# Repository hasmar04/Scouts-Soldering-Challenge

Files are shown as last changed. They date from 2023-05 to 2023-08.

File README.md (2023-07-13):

# Scouts-Soldering-Challenge

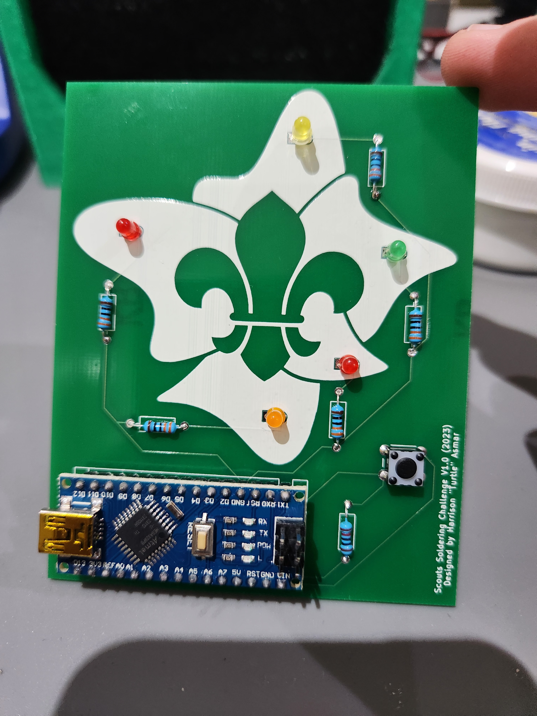
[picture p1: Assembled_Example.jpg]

 
A soldering challenge suitable for Scouts all the way to Rovers.

As a member of the Australian Scouting movement, the logo has been used within this design for the purpose of promoting the movement, and to help the project to the target audience of Scouting members. 

For more information and/or assistance with implementing this challenge in your own Scout group, contact me at [246328@scoutsqld.com.au](mailto:246328@scoutsqld.com.au) 

### For more information on the Australian Scouting Movement, visit https://scouts.com.au

## Components Required
- 1x PCB (see 'pcb' folder)
- 2x Red LED
- 1x Green LED
- 1x Yellow LED
- 1x Orange LED
- 5x 330 ohm resistor
- 1x 10k ohm resistor
- 1x 6x6mm push button
- 1x Arduino Nano

More information can be found in the [Procurement Guide](https://github.com/hasmar04/Scouts-Soldering-Challenge/blob/main/docs/Procurement%20Guide.md)

## Documentation
Documentation can be found in the [/docs](<https://github.com/hasmar04/Scouts-Soldering-Challenge/tree/main/docs>) folder. This includes:
- Arduino IDE Installation and Getting Started
- Arduino Programming Fundamentals
- Procurement Guide
- Assembly Guide

## Contributing
If there is anything that you think is missing from this repository, or you find an error, please [create an issue](<https://github.com/hasmar04/Scouts-Soldering-Challenge/issues>) or fix it yourself and create a pull request.

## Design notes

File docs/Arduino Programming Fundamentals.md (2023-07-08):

# Arduino Programming Fundamentals

## Key Terminology
### Variable
A name that represents a value. Think of it like algebra, where `a` could equal any number, but `a` can also equal words too. Variables can also be changed as the program runs. 
### Library
A set of commands. A library can contain commands that are relevant to each other, such as `Serial` containing commands to do with the Serial Monitor. Think of it like a real library, but instead of books it contains different commands. 

## Key Commands
### I/O (Input, Output)
```
pinMode(PinNumber, Mode)
```
Sets a pin to be either an INPUT or an OUTPUT. 

e.g. `pinMode(2, OUTPUT);`
```
digitalRead(PinNumber)
```
Read the value of the specified PinNumber. This value is usually saved to a variable or used as part of another command. 

e.g. `state = digitalRead(3);`
```
digitalWrite(PinNumber, STATE)
```
Set the digital pin PinNumber to the state HIGH (on) or LOW (off). 

e.g. `digitalWrite(2, HIGH);`

### Serial (Debugging)
#### NOTE: Libraries, Commands and Variable names are all case sensitive, and Serial uses a capital letter!
```
Serial.begin(baud)
```
Begins a Serial transmission over the USB connection to the computer. If using, always use in the `setup()` section. The typical baud rate is 9600. Must be used for other Serial commands to work. 

e.g. `Serial.begin(9600);`
```
Serial.println(string)
```
Prints whatever string (text surrounded by “”) to the serial monitor in the Arduino IDE. Also makes each new command use a new line to make it easier to follow. 

e.g. `Serial.println(“Hello World!”);`

### Other
```
delay(time)
```
Make the program wait for the specified amount of milliseconds (1000 = 1 sec) before proceeding onto the next line.  

e.g. `delay(1000);`

## File Layout
After creating a new file, you will notice that there are two sections, labelled `setup()` and `loop()`. The only things that do **NOT** go in one of these sections are **GLOBAL** variables, i.e. variables that need to be accessible by all parts of the code. All other code, at least for these basic programs, **MUST** go in one of these sections. This includes **CHANGING** the values of those global variables. 

The `setup()` section contains all the code that only runs **ONCE**, such as setting pins to the right modes and enabling `Serial`. 

The `loop()` section, as the name implies, contains all code that is meant to run **FOREVER**. This will be where the bulk of the code should be, such as reading inputs and changing outputs. 

`if()` statements are a form of logic, which allows a program to change it’s behaviour based on if something else is or isn’t true. They only run once, then continue through the rest of the code. For example, if you want to turn the LED on when it is pressed, you could write:
```
if (button == HIGH) {
	digitalWrite(ledRed, HIGH);
}
```
Firstly, you may notice that there are two equals (=) signs. In the Arduino IDE, a single equals is for **SETTING** a value (e.g. Pin = 2), while double equals is for checking if the values are the same as part of logic. 

You will also notice that there are a set of {} brackets, which is how the program knows where the if() statement starts and ends. 

As an extension of `if()` statements, `else if()` can be used for alternative sets of code which can run if the statement provided is true. These run in the order they are found in the code, and the first one that is found to be true will be the **ONLY** one to run. If you want multiple statements which can all run if they are all true, then use multiple `if()` statements instead. 
```
if (button == HIGH) {
	digitalWrite(ledRed, HIGH);
}
else if (button == LOW) {
	digitalWrite(ledRed, LOW);
}
```
`else()` statements are always the last statement in a `if()` statement set, as it is the catch-all for if nothing else is true. For instance, with the example from earlier, if we wanted to turn the light off when the button is **NOT** pressed:
```
if (button == HIGH) {
	digitalWrite(ledRed, HIGH);
}
else {
	digitalWrite(ledRed, LOW);
}
```

Unlike `if()` statements, `while()` loops run through whatever code is contained within them until the statement is no longer true. Any code **AFTER** the `while()` loop will not be run until the statement is no longer true. 
```
while (button == HIGH) {
	digitalWrite(ledRed, HIGH);
}
digitalWrite(ledRed, LOW);
```
For instance, the code above is another way that an LED could be turned on when the button is pressed, and turned off when it is released. The code within the `while()` loop will only run when the statement is true, and the code outside of it will run whenever that statement is not true.

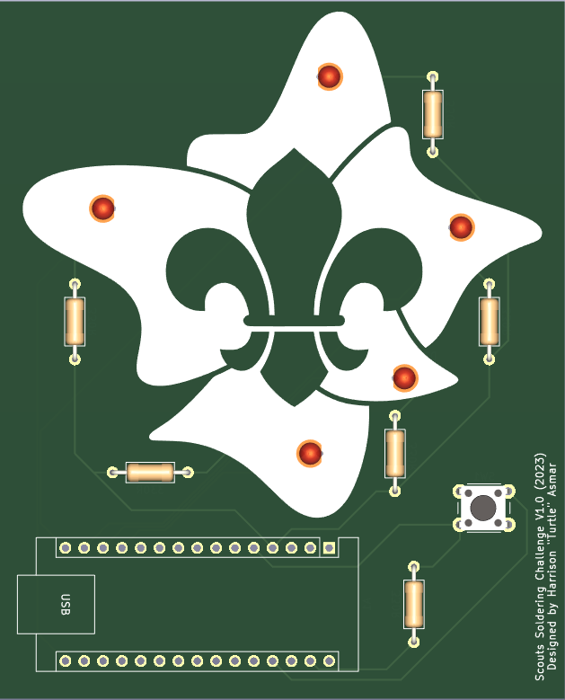
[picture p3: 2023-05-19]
PCB-V1.0.png

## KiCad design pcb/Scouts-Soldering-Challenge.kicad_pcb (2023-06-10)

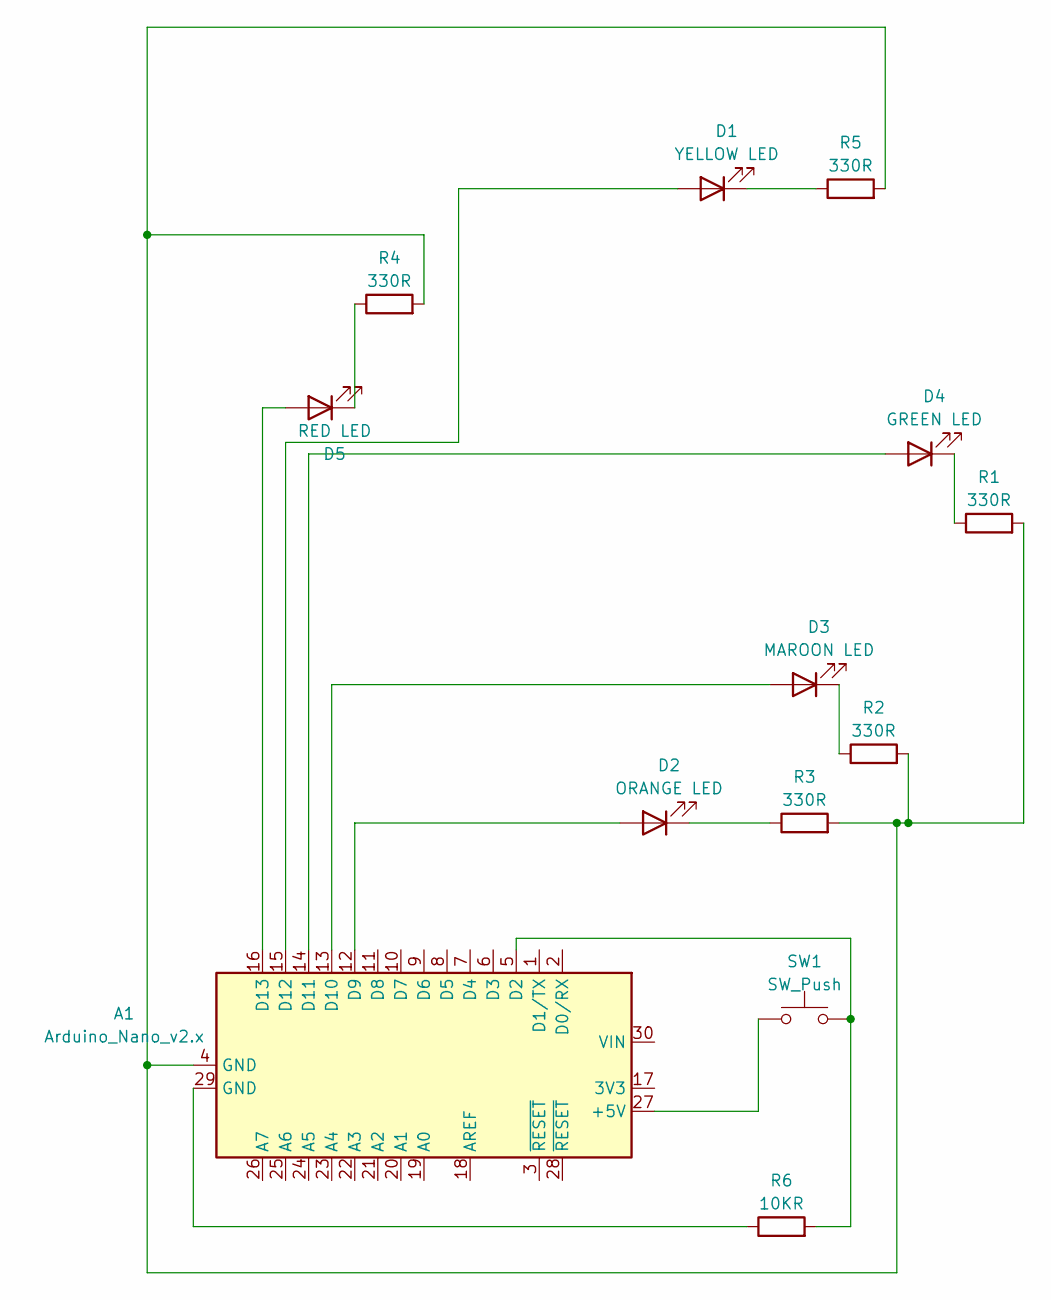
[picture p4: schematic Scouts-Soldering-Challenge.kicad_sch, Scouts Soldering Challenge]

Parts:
A1: Arduino_Nano_v2.x; Arduino_Nano
D1: YELLOW LED; LED_D3.0mm
D2: ORANGE LED; LED_D3.0mm
D3: MAROON LED; LED_D3.0mm
D4: GREEN LED; LED_D3.0mm
D5: RED LED; LED_D3.0mm
R1, R2, R3, R4, R5: 330R; R_Axial_DIN0207_L6.3mm_D2.5mm_P10.16mm_Horizontal
R6: 10KR; R_Axial_DIN0207_L6.3mm_D2.5mm_P10.16mm_Horizontal
SW1: SW_Push; SW_PUSH_6mm

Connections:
unnamed: A1.27 (+5V), SW1.1
unnamed: A1.5 (D2), R6.2, SW1.2
unnamed: A1.12 (D9), D2.2 (A)
unnamed: A1.13 (D10), D3.2 (A)
unnamed: A1.14 (D11), D4.2 (A)
unnamed: A1.15 (D12), D1.2 (A)
unnamed: A1.16 (D13), D5.2 (A)
unnamed: A1.4 (GND), R1.2, R2.2, R3.2, R4.2, R5.2
unnamed: A1.29 (GND), R6.1
unnamed: D1.1 (K), R5.1
unnamed: D2.1 (K), R3.1
unnamed: D3.1 (K), R2.1
unnamed: D4.1 (K), R1.1
unnamed: D5.1 (K), R4.1

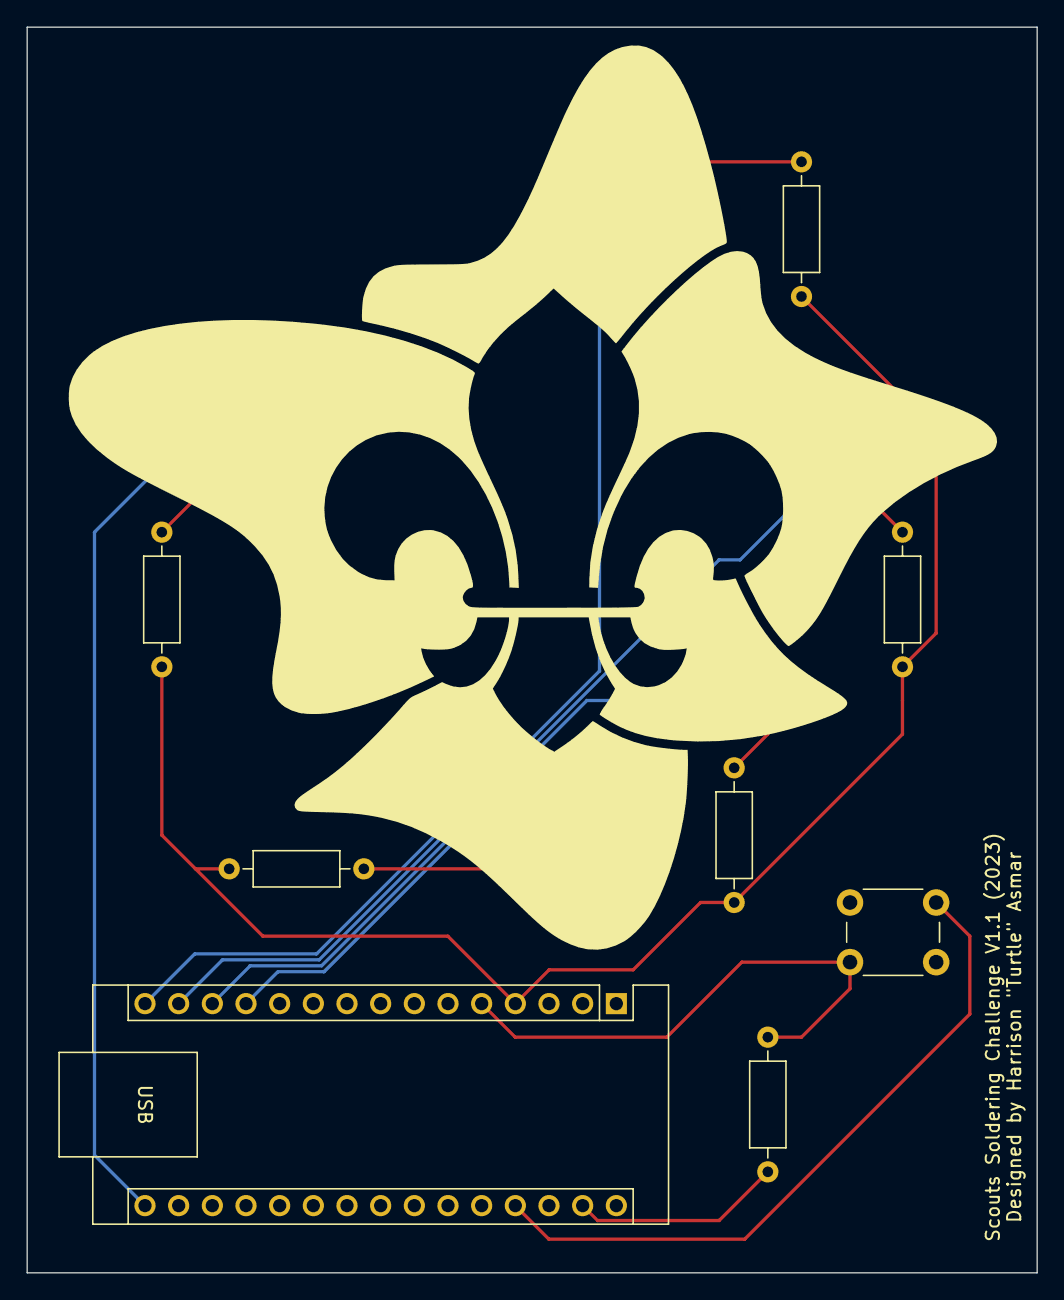
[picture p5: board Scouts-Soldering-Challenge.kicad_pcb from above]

Board: 2 copper layers, 76.2 x 94.0 mm, 13 parts (0 on the bottom side), 14 nets.

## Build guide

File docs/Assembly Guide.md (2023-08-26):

# Assembly Guide
## Before Proceeding
Ensure that you have all components listed in the [Procurement Guide](https://github.com/hasmar04/Scouts-Soldering-Challenge/blob/main/docs/Procurement%20Guide.md), as well as a soldering iron and some solder. Lead-free solder is recommended, although it does require a higher temperature on the soldering iron. 
## Step 1: Test Arduinos
Before starting on the assembly, it is a good idea to test the Arduinos to ensure they are functioning correctly and code can be uploaded to them. It is recommended to upload the boardTest code by following the [Arduino IDE Installation and Getting Started](https://github.com/hasmar04/Scouts-Soldering-Challenge/blob/main/docs/Arduino%20IDE%20Installation%20&%20Getting%20Started%20V1.0.pdf) guide. 
## Step 2: Sort Components Into Sets
This is recommended to be done before the night to make it easier to get the Scouts started on the project. Check out the [README](../README.md) for the list of required components. 
## Step 3: Start with the Resistors
It is always a good idea to start with the flattest components, which in this project are the resistors. There is no wrong orientation to install them, but make sure the correct resistors are installed in the correct places. Poke the legs of the resistor through the holes, trying to make it as flat against the PCB as possible. Once in place, solder from the back side of the PCB and cut the excess legs off with sidecutters. 
## Step 4: Move onto the LEDs
The LEDs are the next tallest components, and require slighly more care than the resistors to install. Ensure the short leg of the LED goes to the square pad, putting it the other way around will not work. The legs can be bent to hold it in place. Once soldered in place, cut off extra leg length with sidecutters. For future reference, the square pad is typically for Ground, and the round pad for Power. The short leg of the LED is always for Ground, while the long leg is for Power. 
## Step 5: Insert and Solder the Button
The button has no polarity, and can go in either way. It should grab onto the PCB, making soldering it in place a breeze. Once soldered, and excess leg can be removed if desired. 
## Step 6: Solder the Arduino into Place.
The component which is tallest and also requires the most work is the Arduino itself. All the legs, even those not used, should be soldered in place. Make sure the Arduino is orrientated the correct way, so that the USB port lines up with the white box on the silskcreen (the white lines in the PCB). It is recommended to start with soldering two opposite corners to ensure the Arduino doesn't move as it is being soldered. Once all the legs are soldered, use sidecutters to remove excess leg length. 
## Step 7: Test!
Plug the Arduino into power and ensure that the button and the LEDs are all working as intended.

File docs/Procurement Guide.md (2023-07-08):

 # Procurement Guide
For most people wanting to complete this project with a group, Element14 (au.element14.com) is the best place to acquire components from. They are based in Australia, and have pricing very similar to buying directly from suppliers overseas using a site such as Alibaba. 

Key characteristics that are needed when finding components:
- Arduino Nano – headers attached (pins along the sides)
- LEDs – through-hole, 3mm casing
- Push button – case dimensions of 6x6mm, 4 legs, through-hole, single-pole single-throw (SPST)
- Resistors – resistances of 330ohm and 1kohm, through-hole. Does not need to be more than 500mW or have a resistance tolerance of less than 1%. 

Below is a list of parts that were available at the time of writing that would be suitable for this project:
- Arduino Nano - https://au.element14.com/seeed-studio/102010268/seeeduino-board-arduino-nano-board/dp/3932117 
- 3mm Red LED - https://au.element14.com/kingbright/l-1334surtk/led-3mm-red-630nm-red-transparent/dp/4062027
- 3mm Green LED - https://au.element14.com/multicomp/703-0087/led-green-3mm-572nm-standard/dp/2112096 
- 3mm Orange LED - https://au.element14.com/multicomp/mcl034at/led-3mm-32-orange/dp/1581126 
- 3mm Yellow LED - https://au.element14.com/lumex/ssl-lx3044yc/led-3mm-yellow-90mcd-585nm/dp/7605560 
- 6x6mm push button - https://au.element14.com/apem/mjtp1230/switch-tactile-spst-50ma-through/dp/4511189 
- 330ohm resistor - https://au.element14.com/multicomp-pro/mcmf0w4ff3300a50/metal-film-resistor-330-ohm-250mw/dp/1126972 
- 1kohm resistor - https://au.element14.com/multicomp-pro/mcmf0w4ff1001a50/metal-film-resistor-1kohm-250mw/dp/1126919 

If these parts are not available, there should be similar components available. Element14 also has the option to search for similar products based of characteristics like size and colour.

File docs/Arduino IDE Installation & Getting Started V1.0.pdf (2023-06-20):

# Arduino IDE Installation & Getting Started

1. Download the latest version of the IDE from https://www.arduino.cc/en/software
2. Run the installer
Ensure your Arduino Nano is plugged into your computer and the Red power LED is illuminated.
1. Open the ‘boardTest.ino’ file which you were given in the Arduino IDE. This will be used to test that everything is working correctly.
2. Open the ‘Tools’ Menu in the top menu bar

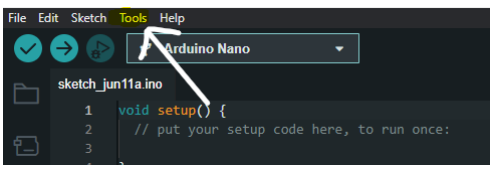
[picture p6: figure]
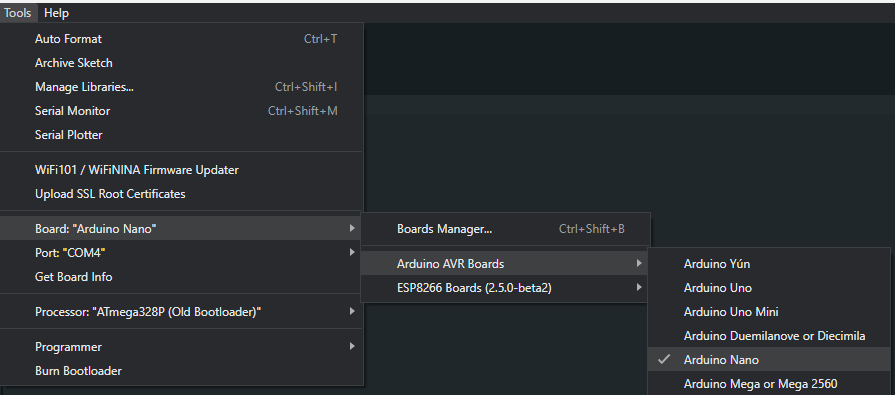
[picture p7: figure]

3. Select ‘Arduino Nano’ under ‘Board’, then ‘Arduino AVR Boards’

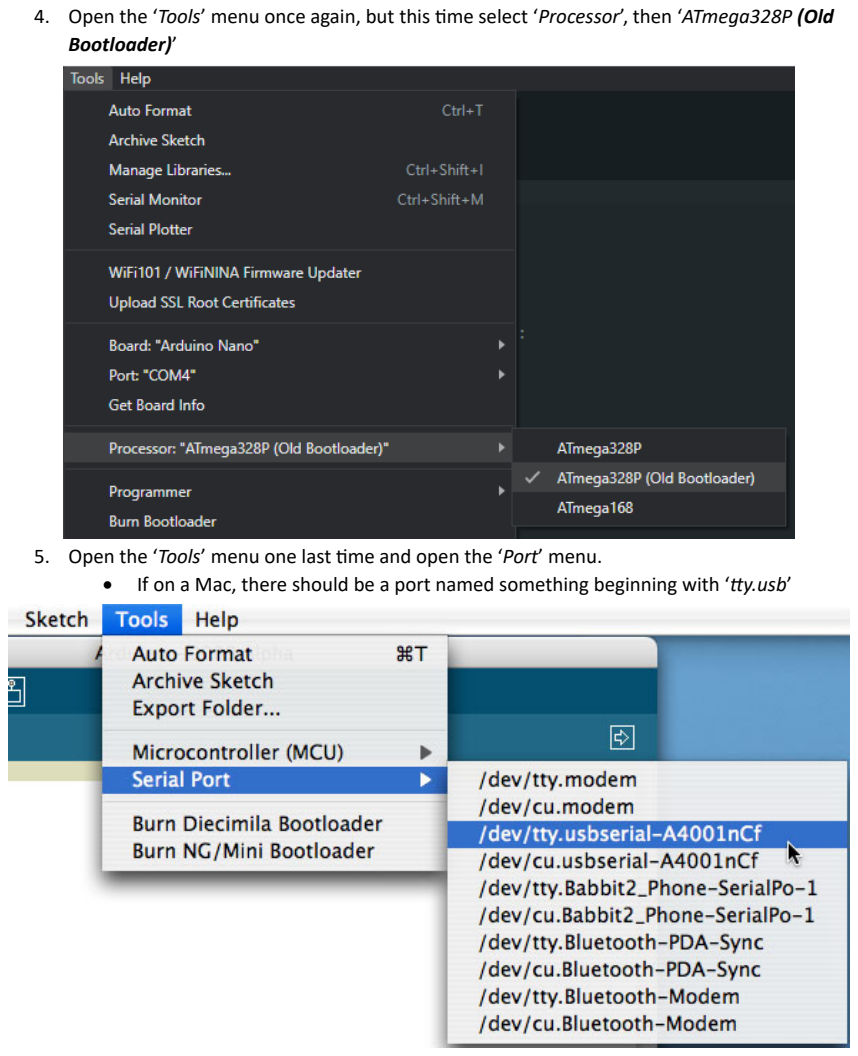
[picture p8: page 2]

4. Open the ‘Tools’ menu once again, but this time select ‘Processor’, then ‘ATmega328P (Old Bootloader)’
5. Open the ‘Tools’ menu one last time and open the ‘Port’ menu.
- If on a Mac, there should be a port named something beginning with ‘tty.usb’

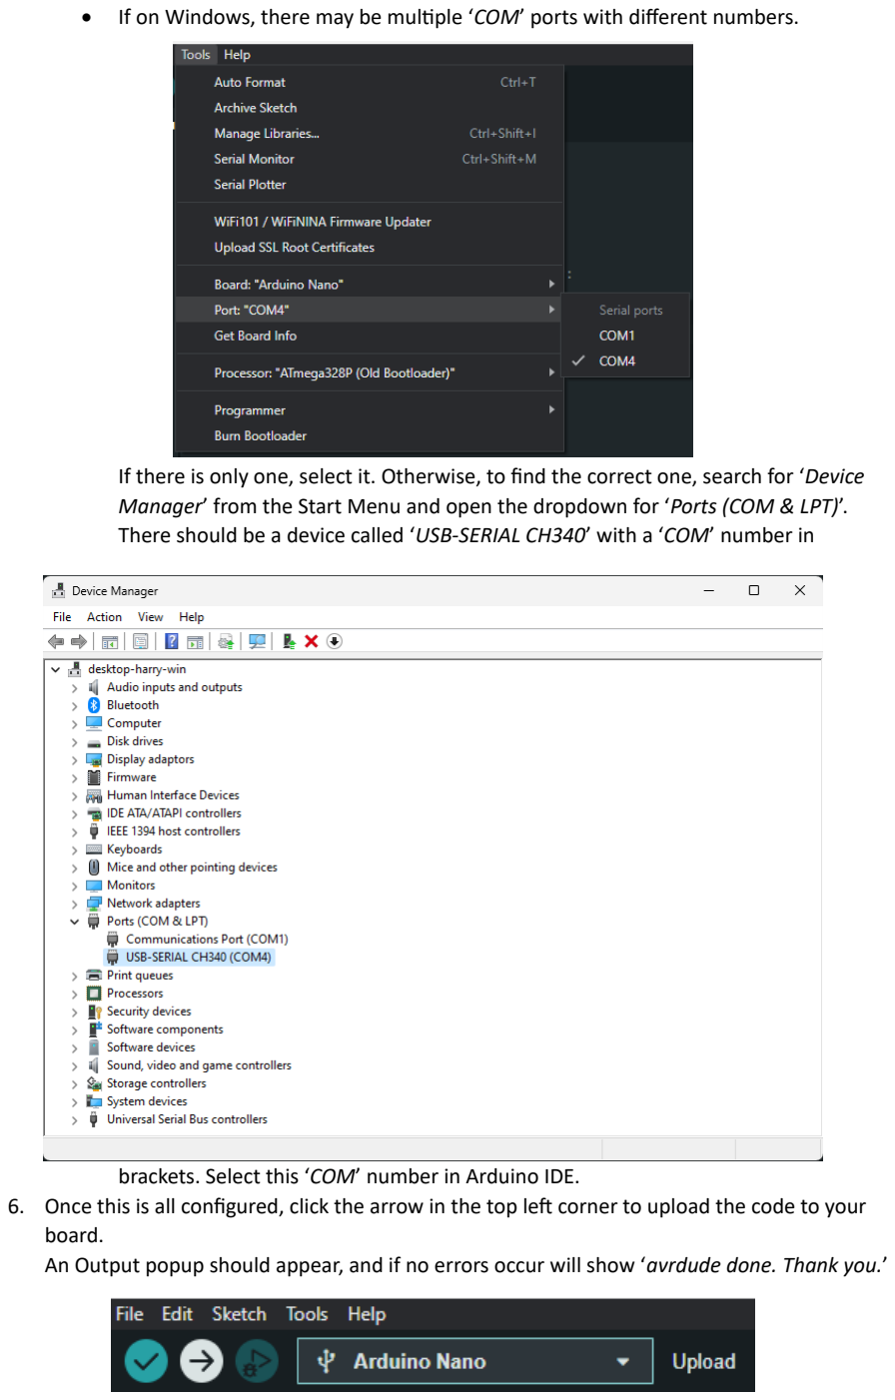
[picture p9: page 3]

- If on Windows, there may be multiple ‘COM’ ports with different numbers.

If there is only one, select it. Otherwise, to find the correct one, search for ‘Device Manager’ from the Start Menu and open the dropdown for ‘Ports (COM & LPT)’. There should be a device called ‘USB-SERIAL CH340’ with a ‘COM’ number in

brackets. Select this ‘COM’ number in Arduino IDE.
6. Once this is all configured, click the arrow in the top left corner to upload the code to your board.
An Output popup should appear, and if no errors occur will show ‘avrdude done. Thank you.’

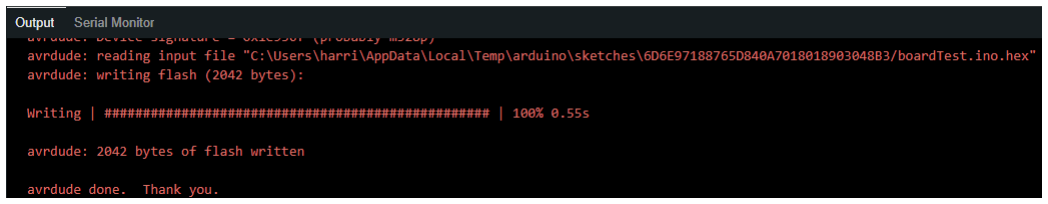
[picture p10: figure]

If an error occurs, please ask for assistance.
7. To test that everything is working correctly, press the button you soldered to the circuit board and all five LEDs should light up. If not, please ask for assistance.

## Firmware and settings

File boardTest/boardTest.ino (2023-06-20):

/*
  Scouts-Soldering-Challenge Board Test

  The button enables the LEDs on the board, and all LEDs should light up when the button is pressed. 

  Based off the Arduino Example "Button"
  Created by Harrison "Turtle" Asmar

  Version 1 - 10/06/2023
*/

// constants won't change. They're used here to set pin numbers:
const int buttonPin = 2;  // the number of the pushbutton pin
const int ledRed = 13;    // the number of the LED pin
const int ledYellow = 12;    // the number of the LED pin
const int ledGreen = 11;    // the number of the LED pin
const int ledMaroon = 10;    // the number of the LED pin
const int ledOrange = 9;    // the number of the LED pin

// variables will change:
int buttonState = 0;  // variable for reading the pushbutton status

void setup() {
  // initialize the LED pin as an output:
  pinMode(ledRed, OUTPUT);
  pinMode(ledYellow, OUTPUT);
  pinMode(ledGreen, OUTPUT);
  pinMode(ledMaroon, OUTPUT);
  pinMode(ledOrange, OUTPUT);
  // initialize the pushbutton pin as an input:
  pinMode(buttonPin, INPUT);
  Serial.begin(9600);
}

void loop() {
  // read the state of the pushbutton value:
  buttonState = digitalRead(buttonPin);

  // check if the pushbutton is pressed. If it is, the buttonState is HIGH:
  if (buttonState == HIGH) {
    // turn LED on:
    digitalWrite(ledRed, HIGH);
    digitalWrite(ledYellow, HIGH);
    digitalWrite(ledGreen, HIGH);
    digitalWrite(ledMaroon, HIGH);
    digitalWrite(ledOrange, HIGH);
    Serial.println("HIGH");
  } else {
    // turn LED off:
    digitalWrite(ledRed, LOW);
    digitalWrite(ledYellow, LOW);
    digitalWrite(ledGreen, LOW);
    digitalWrite(ledMaroon, LOW);
    digitalWrite(ledOrange, LOW);
  }
}

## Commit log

2023-05-19 Added PCBway exports to gitignore
    Prevents PCBway plugin archives from being uploaded to repo
2023-05-19 Added render of PCB V1.0
2023-05-19 Created PCB and schematic
    Created schematic and two PCB designs, one larger but too expensive to make, and a smaller, more economical design. Both contain the same amount of parts.
    [Scouts-Soldering-Challenge - Big.kicad_pcb, Scouts-Soldering-Challenge.kicad_pcb, Scouts-Soldering-Challenge.kicad_sch]
2023-05-29 Updated some trace routes
    Minor changes, still functionally the same
    [Scouts-Soldering-Challenge.kicad_pcb]
2023-06-10 Created board test code
    Allows for testing of the button and all the LEDs at once. Also outputs to the Serial Monitor in case LEDs are not working.
    [boardTest.ino]
2023-06-10 Corrected mistake in PCB
    Wiring is all still the same, but the pins on the LED were connected in the wrong orientation, meaning the PCB showed the LED rotated the wrong way.
    [Scouts-Soldering-Challenge.kicad_sch]
2023-06-10 Rotated LEDs to adapt to updated schematic
    LEDs now have the correct leg connecting to the square ground pad. Old PCB design still works, but this is now in line with standard design principles.
    [Scouts-Soldering-Challenge.kicad_pcb]
2023-06-10 Bumped PCB Version to V1.1
    [Scouts-Soldering-Challenge.kicad_pcb]
2023-06-10 Fixed mistake of disconnected component
    In the process of correcting the schematic changes, I disconnected one of the LEDs and forgot to reconnect it. This has been rectified.
    [Scouts-Soldering-Challenge.kicad_pcb]
2023-06-10 Added image to README
    Added example assembled board image to README
2023-06-20 boardTest - Serial now prints on new lines
2023-06-20 Create Arduino IDE Installation & Getting Started V1.0.pdf
    Brief guide on installing the IDE and testing that the Arduino is connected and all components are working.
2023-06-20 Updated boardTest
    Updated boardTest to make variable names match silkscreened values on PCB.
2023-06-21 Renamed pcb files folder to /pcb
    Makes finding files easier, repository should make more sense in how it is laid out now.
    [Scouts-Soldering-Challenge - Big.kicad_pcb, Scouts-Soldering-Challenge.kicad_pcb, Scouts-Soldering-Challenge.kicad_sch]
2023-06-21 Update README - Contact details and required parts
    Added my contact email and the fact a PCB is required for the project.
2023-07-08 Converted some docs to markdown
    Converted the Arduino Programming Fundamentals and Procurement Guide to markdown, allows for easier code contribution by others without needing two separate documents in the repository.
    Did not convert Arduino IDE guide as it contains many images and would take too long to convert, and it should never need many updates.
2023-08-26 Create Assembly Guide.md
